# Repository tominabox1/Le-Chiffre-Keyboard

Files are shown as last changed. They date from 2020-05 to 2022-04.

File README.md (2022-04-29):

# Le Chiffre (ironically, "the number" in French)
The purpose of the board is to provide a platform for MX and Choc ergo (Alps support too!) in one package for when ones wrists need a break. The board supports an RGB LED strip with DI on port F0. The board is also fitted with support for run-of-the-mill .91" OLED and EC11 rotary encoder.

Great thanks goes to Jake at P3D for really making the case amazing and open sourcing his work. Check him out at P3Dstore.com

Firmware for the keyboard is available here: https://github.com/qmk/qmk_firmware/tree/master/keyboards/tominabox1/le_chiffre

This project is open sourced with the GPL-3.0 license. The license conditionally allows for commercial use, modification, distribution, patent, and private use. Please take note of the license conditions before utilizing this project. 

## Bill of materials
You can copy this table when ordering PCBs. 
| Item # | *Ref Des | *Qty | *Mfg Part # | Description\Value | *Package |
|---|---|---|---|---|---|
| 1 | D1, D2, D3, D4, D5, D6, D7, D8, D9, D10, D11, D12, D13, D14, D15, D16, D17, D18, D19, D20, D21, D22, D23, D24, D25, D26, D27, D28, D29, D30, D31, D32, D33, D34, D35 | 35 | 1N4148W | | SOD-123 |
| 2 | R7, R8 | 2 | 0603WAF4701T5E | 4.7k | 0805 |
| 3 | R6, R5 | 2 | 0805W8F1002T5E | 10k | 0805 |
| 4 | R4, R3 | 2 | 0805W8F220JT5E | 22r | 0805 |
| 5 | R2, R1 | 2 | 0805W8F5101T5E | 5.1k | 0805 |
| 6 | SW1 | 1 | TS-1076S-A1B2 | SW_Push | SMD,5.2x5.2x1.5  |
| 7 | F1 | 1 | SMD0805-020 | | 0805 |
| 8 | C8 | 1 | GRM188R60J475KE19D | 4.7uF | 0603 |
| 9 | C7, C5, C2, C1 | 4 | GRM188R71H104KA93D | 0.1uF | 0603 |
| 10 | C6, C3 | 2 | GRM1882C1H220JA01D | 22pf | 0603 |
| 11 | C4 | 1 | CC0603KRX5R6BB105  | 1uF | 0603 |
| 12 | Y1 | 1 | X322516MLB4SI | 16MHz | 3.2x2.5mm, 4 pad |
| 13 | U1 | 1 | ATMEGA32U4-AU | | 44-TQFP |
| 14 | USB1 | 1 | TYPE-C-31-M-12 | | |
| 15 | D111, D110, D109, D108, D107, D106, D105, D104, D103, D102, D101 | 11 | WS2812B-B | | LED-4_5050 |

# Fab files
If you just want to order PCBs and plates, just grab these files and send them to your fab house. Also include the BOM from above.

[PCB](KiCad/Le%20Chiffre%20v2/Fab/PCB/LeChiffrePCBFab.zip)

[Plate](KiCad/Le%20Chiffre%20v2/Fab/Plate/LeChiffrePlateFab.zip) (this is for one side, order 2 for each PCB)

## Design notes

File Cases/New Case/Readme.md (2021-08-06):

This case uses m2 heatset inserts on the top and m2 hardware for the bottom. Print with large flat faces on the print bed. I suggest using internal brim on the top piece so that the sharp corners do not curl.

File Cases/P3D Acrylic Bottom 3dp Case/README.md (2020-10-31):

# Le Chiffre

Le Chiffre
This is the STL for the Le Chiffre keyboard designed by tominabox1 (discord @tominabox1#7884)

This model is designed for MX switches and the fr4 plates provided in the group buy(s). Feel free to modify as you wish!

Visit the QMK page for firmware information.

P3D Mod Cases do not have the option for an OLED cover. They use 8 m2x8mm screws
Print them Top Down on the bed.
The Incline bottom is printed with the top part down, and the USB bump is bridged. No supports needed. 

Optionally, for the P3D cases, an OLED bezel designed by u/bomtarnes can be printed and friction fitted (chiffoled3.stl).

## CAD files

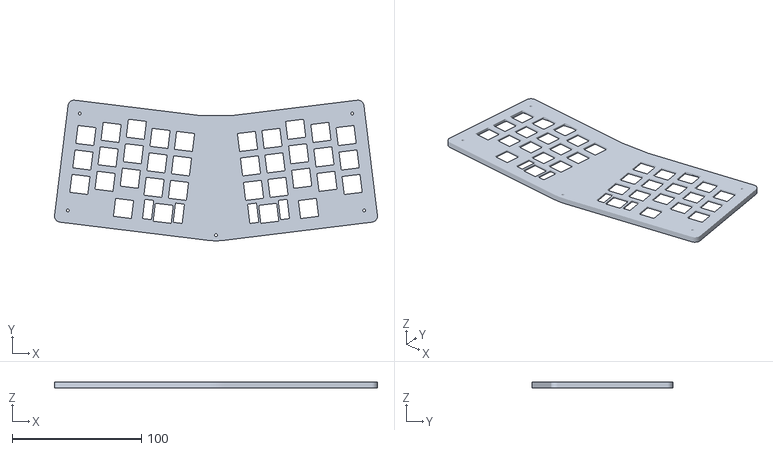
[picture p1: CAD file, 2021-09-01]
Cases/New Case/Plate.stl
249.6 x 108.7 x 4.50

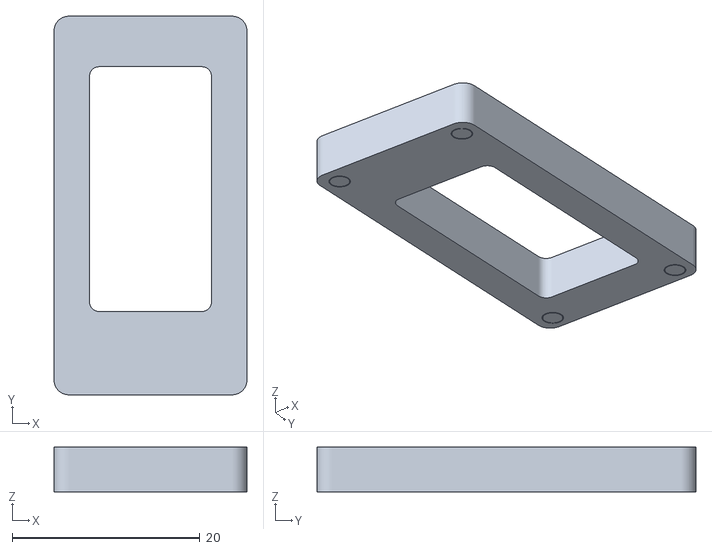
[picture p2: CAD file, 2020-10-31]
Cases/OG Case/chiffoled3.stl
20.6 x 40.4 x 4.79

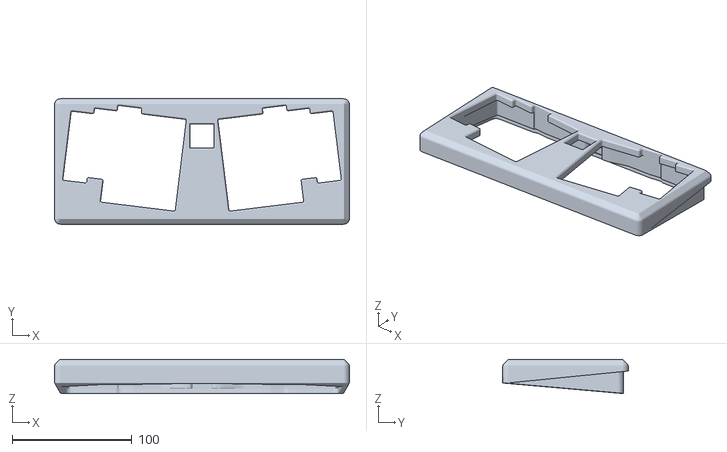
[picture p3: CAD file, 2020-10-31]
Cases/P3D Acrylic Bottom 3dp Case/Le Chiffre MX Cutout No OLED Cutout acrylic bottom.stl
246.5 x 104.9 x 28.5

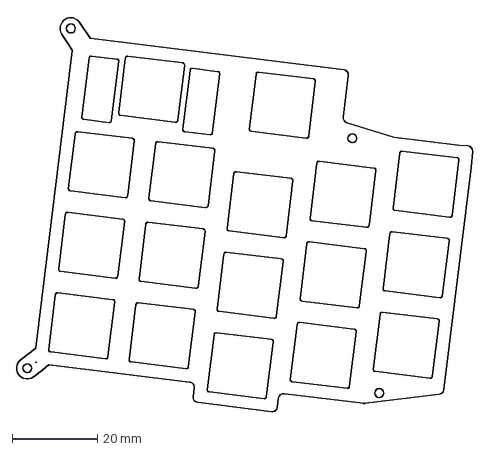
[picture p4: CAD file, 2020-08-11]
KiCad/Le Chiffre v2/LeChiffre_Plate/Plate 5.14.32 PM.dxf
107.2 x 92.9 mm

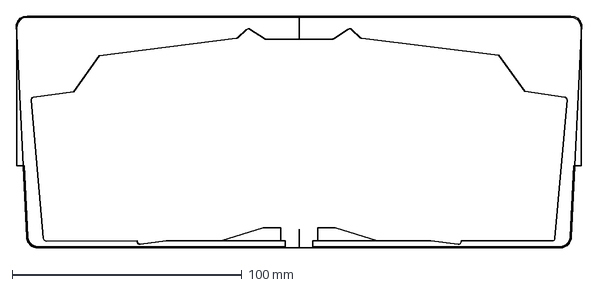
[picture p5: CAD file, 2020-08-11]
KiCad/Le Chiffre v2/plate.dxf
246.1 x 100.9 mm

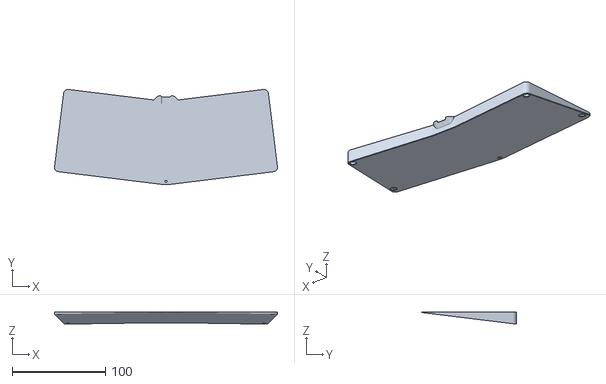
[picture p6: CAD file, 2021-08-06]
Cases/New Case/Bottom.stl
239.5 x 102.1 x 13.1

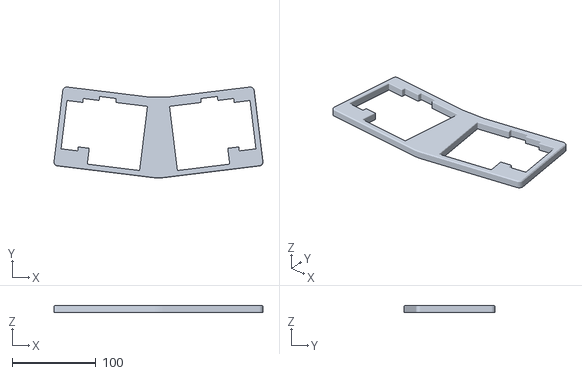
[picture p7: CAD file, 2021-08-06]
Cases/New Case/Top.stl
249.6 x 108.7 x 8.00

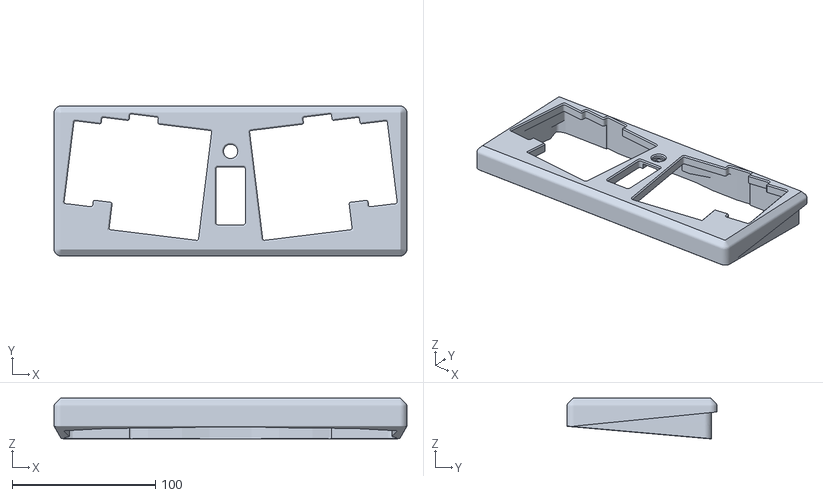
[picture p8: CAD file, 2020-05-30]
Cases/OG Case/Le Chiffre Incline top No Cover P3D Mod.stl
246.5 x 104.9 x 28.5

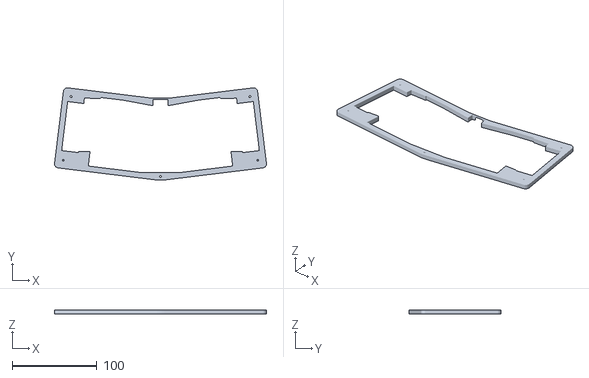
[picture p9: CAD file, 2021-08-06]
Cases/New Case/Bottom Mid.stl
249.6 x 108.7 x 5.00

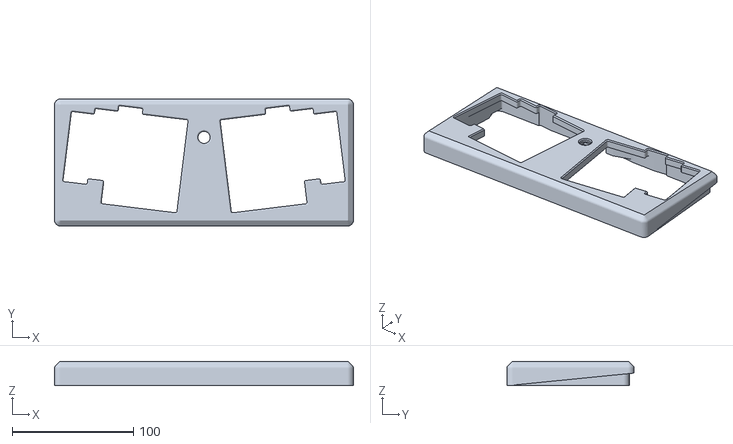
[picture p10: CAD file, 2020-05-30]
Cases/OG Case/Le Chiffre Flat Top with Cover P3D Mod.stl
246.5 x 104.9 x 20.1

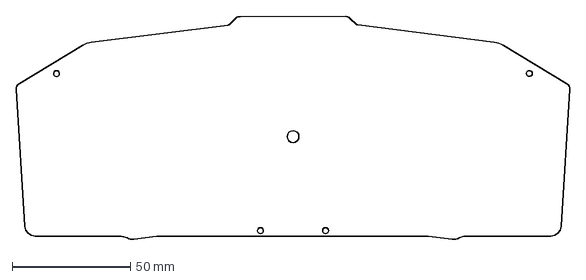
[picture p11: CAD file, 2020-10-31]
Cases/P3D Acrylic Bottom 3dp Case/Acrylic Bottom Le Chiffre P3D Mod v7.dxf
234.3 x 94.4 mm

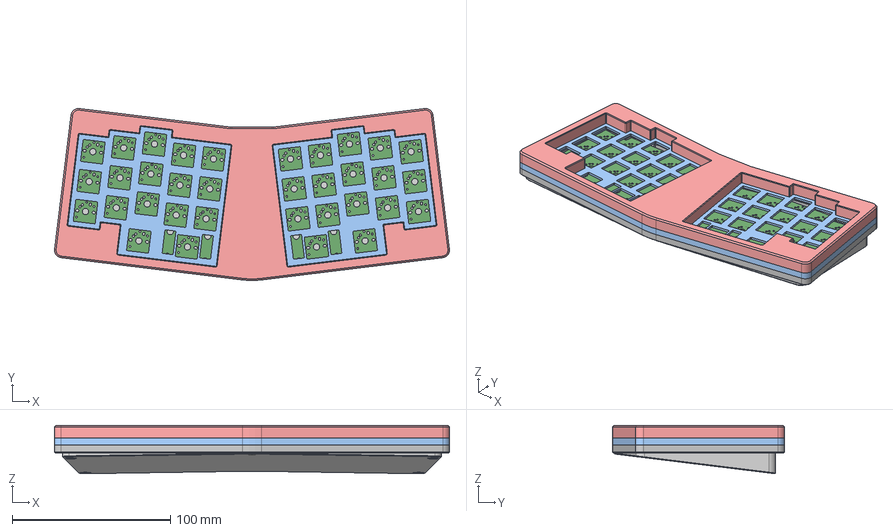
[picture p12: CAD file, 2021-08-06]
Cases/New Case/Le Chiffre New 2021.step
249.6 x 108.7 x 30.6 mm
HRO TYPE-C-31-M-12

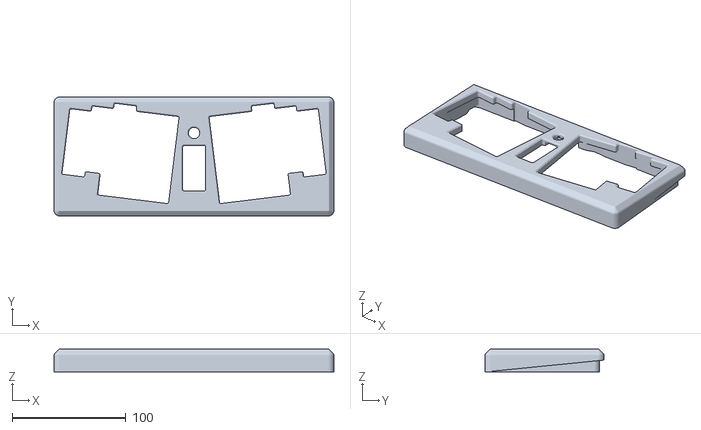
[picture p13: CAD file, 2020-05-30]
Cases/OG Case/Le Chiffre Flat Top No Cover P3D Mod.stl
246.5 x 104.9 x 20.1

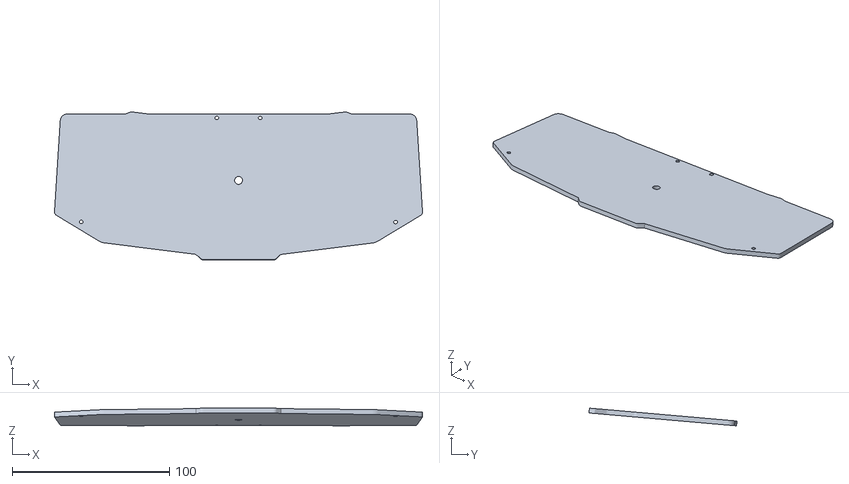
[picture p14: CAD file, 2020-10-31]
Cases/P3D Acrylic Bottom 3dp Case/Le Chiffre Acylic Bottom stl.stl
234.2 x 94.2 x 11.3

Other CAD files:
Cases/OG Case/Le Chiffre Incline top with Cover P3D Mod.stl
Cases/P3D Acrylic Bottom 3dp Case/Le Chiffre Rotary No OLED Cutout Acrylic Bottom.stl
Cases/P3D Acrylic Bottom 3dp Case/Le Chiffre Rotary OLED Cutout Acrylic Bottom.stl
Cases/OG Case/Le Chiffre Incline Bottom P3D Mod.stl
Cases/OG Case/Bottom Left.stl
Cases/OG Case/Le Chiffre v16.step
Cases/OG Case/bottom Right.stl
Cases/P3D Acrylic Bottom 3dp Case/Le Chiffre MX Cutout OLED Cutout acrylic bottom.stl

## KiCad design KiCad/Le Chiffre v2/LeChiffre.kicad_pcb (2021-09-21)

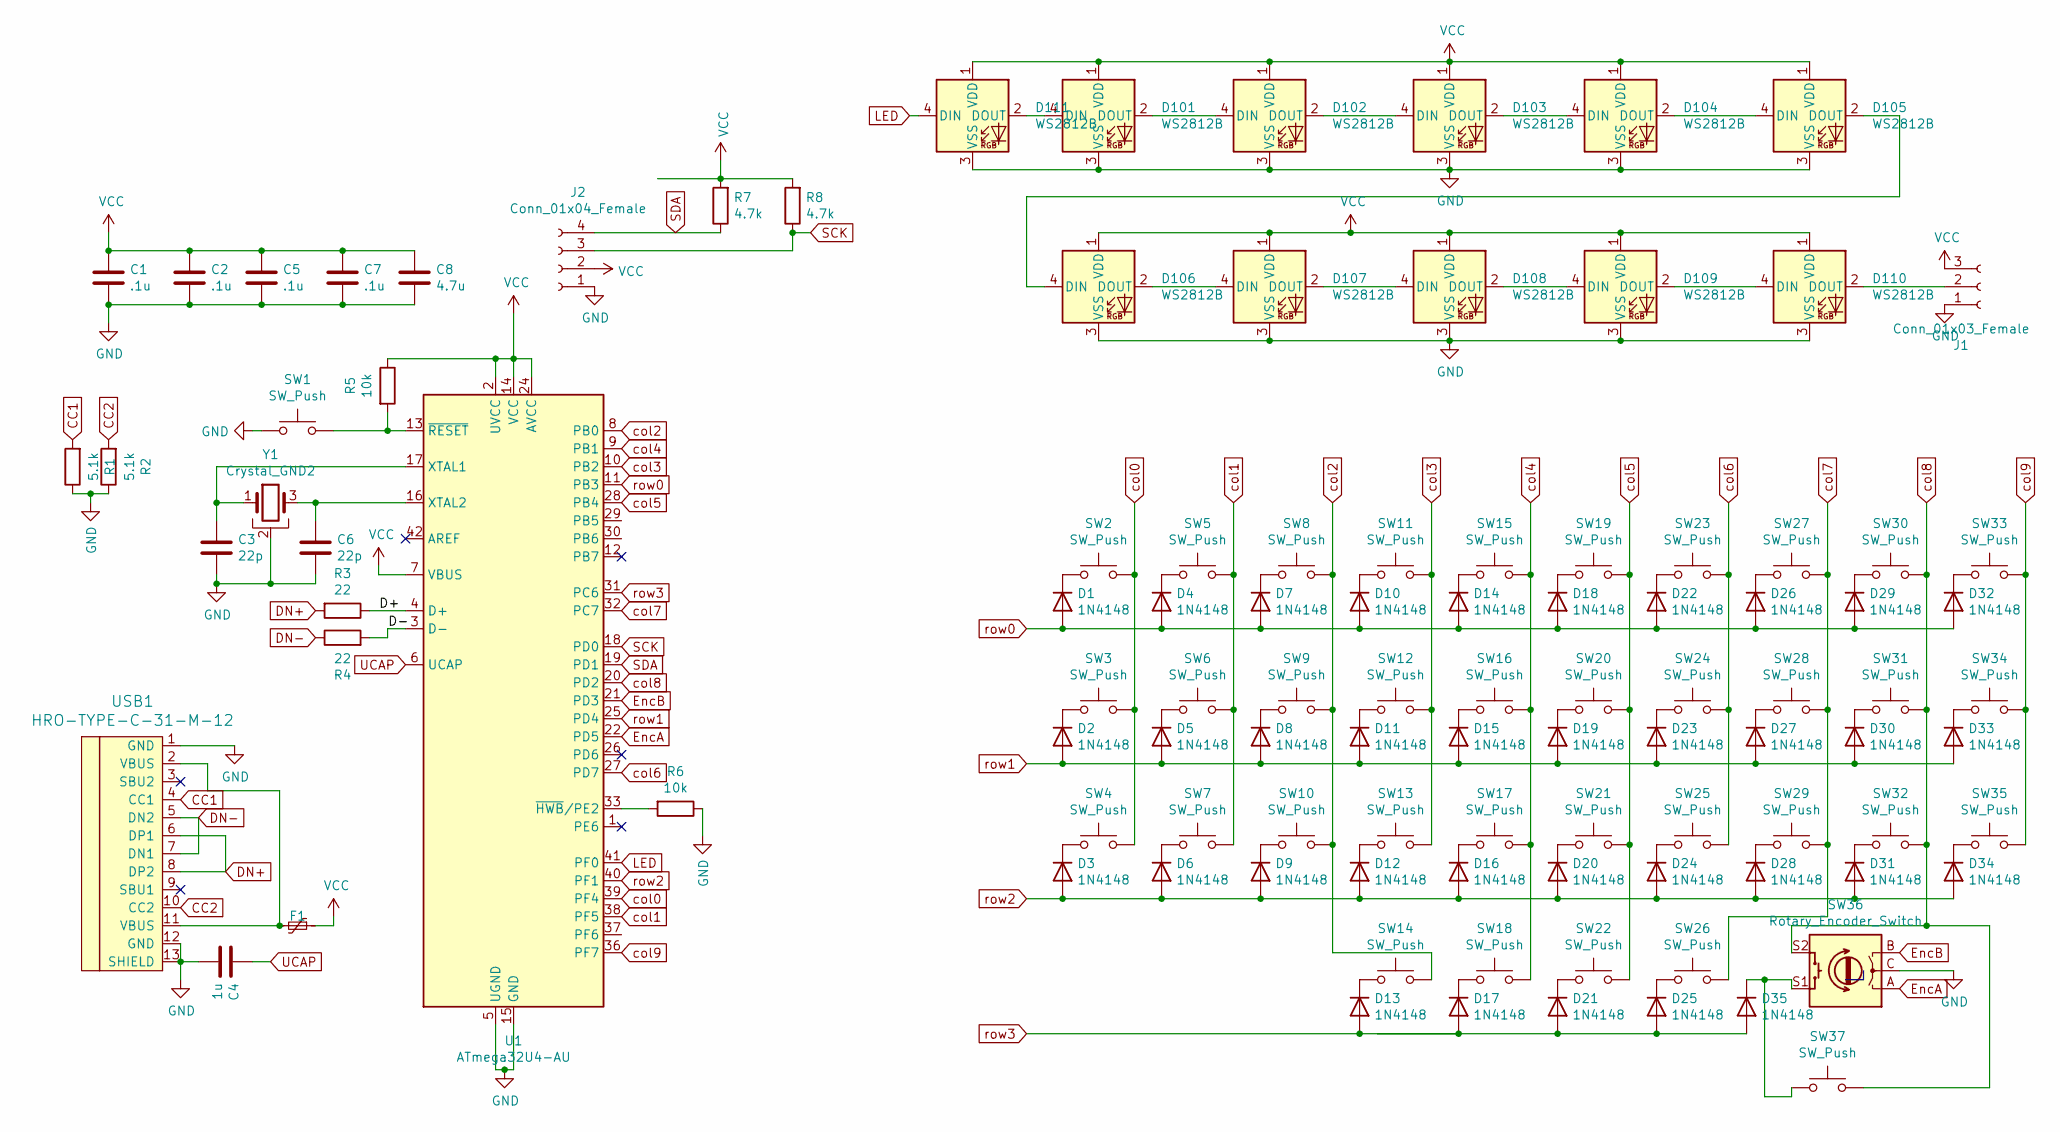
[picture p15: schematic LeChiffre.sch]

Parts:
C1, C2, C5, C7: .1u; C_0603
C3, C6: 22p; C_0603
C4: 1u; C_0603
C8: 4.7u; C_0603
D1, D2, D3, D4, D5, D6, D7, D8, D9, D10, D11, D12, D13, D14, D15, D16, D17, D18, D19, D20, D21, D22, D23, D24, D25, D26, D27, D28, D29, D30, D31, D32, D33, D34, D35: 1N4148; D_SOD123
D101, D102, D103, D104, D105, D106, D107, D108, D109, D110, D111: WS2812B; LED_WS2812B_PLCC4_5.0x5.0mm_P3.2mm
F1: Polyfuse_Small; Fuse_0805
J1: Conn_01x03_Female; PinSocket_1x03_P2.54mm_Vertical
J2: Conn_01x04_Female; PinSocket_1x04_P2.54mm_Vertical
R1, R2: 5.1k; R_0805
R3, R4: 22; R_0805
R5, R6: 10k; R_0805
R7, R8: 4.7k; R_0805
SW1: SW_Push; SW_SPST_TL3342
SW2, SW3, SW4, SW5, SW6, SW7, SW8, SW9, SW10, SW11, SW12, SW13, SW14, SW15, SW16, SW17, SW19, SW20, SW21, SW23, SW24, SW25, SW26, SW27, SW28, SW29, SW30, SW31, SW32, SW33, SW34, SW35, SW37: SW_Push; MX-Alps-Choc-1U-NoLED
SW18, SW22: SW_Push; MX-Alps-Choc-2U-StabFlip
SW36: Rotary_Encoder_Switch; RotaryEncoder_Alps_EC12E-Switch_Vertical_H20mm_CircularMoun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
U1: ATmega32U4-AU; ATMEGA32U4-AU
USB1: HRO-TYPE-C-31-M-12; HRO-TYPE-C-31-M-12-HandSoldering
Y1: Crystal_GND2; Crystal_SMD_3225-4pin_3.2x2.5mm

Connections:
/D+: R3.1, U1.4 (D+)
/D-: R4.2, U1.3 (D-)
CC1: R1.2, USB1.4 (CC1)
CC2: R2.2, USB1.10 (CC2)
DN+: R3.2, USB1.6 (DP1), USB1.8 (DP2)
DN-: R4.1, USB1.5 (DN2), USB1.7 (DN1)
EncA: SW36.A, U1.22 (PD5)
EncB: SW36.B, U1.21 (PD3)
GND: C1.2, C2.2, C3.2, C4.2, C5.2, C6.2, C7.2, C8.2, D101.3 (VSS), D102.3 (VSS), D103.3 (VSS), D104.3 (VSS), D105.3 (VSS), D106.3 (VSS), D107.3 (VSS), D108.3 (VSS), D109.3 (VSS), D110.3 (VSS), D111.3 (VSS), J1.1 (Pin_3), J2.1, R1.1, R2.1, R6.1, SW1.1, SW36.C, U1.5 (UGND), U1.15 (GND), U1.23 (GND), U1.35 (GND), U1.43 (GND), USB1.1 (GND), USB1.12 (GND), USB1.13 (SHIELD), Y1.2
LED: D111.4 (DIN), U1.41 (PF0)
unnamed: C3.1, U1.17 (XTAL1), Y1.1
unnamed: C6.1, U1.16 (XTAL2), Y1.3
unnamed: D1.1 (K), SW2.1
unnamed: D2.1 (K), SW3.1
unnamed: D3.1 (K), SW4.1
unnamed: D4.1 (K), SW5.1
unnamed: D5.1 (K), SW6.1
unnamed: D6.1 (K), SW7.1
unnamed: D7.1 (K), SW8.1
unnamed: D8.1 (K), SW9.1
unnamed: D9.1 (K), SW10.1
unnamed: D10.1 (K), SW11.1
unnamed: D11.1 (K), SW12.1
unnamed: D12.1 (K), SW13.1
unnamed: D13.1 (K), SW14.1
unnamed: D14.1 (K), SW15.1
unnamed: D15.1 (K), SW16.1
unnamed: D16.1 (K), SW17.1
unnamed: D17.1 (K), SW18.1
unnamed: D18.1 (K), SW19.1
unnamed: D19.1 (K), SW20.1
unnamed: D20.1 (K), SW21.1
unnamed: D21.1 (K), SW22.1
unnamed: D22.1 (K), SW23.1
unnamed: D23.1 (K), SW24.1
unnamed: D24.1 (K), SW25.1
unnamed: D25.1 (K), SW26.1
unnamed: D26.1 (K), SW27.1
unnamed: D27.1 (K), SW28.1
unnamed: D28.1 (K), SW29.1
unnamed: D29.1 (K), SW30.1
unnamed: D30.1 (K), SW31.1
unnamed: D31.1 (K), SW32.1
unnamed: D32.1 (K), SW33.1
unnamed: D33.1 (K), SW34.1
unnamed: D34.1 (K), SW35.1
unnamed: D35.1 (K), SW36.S1, SW37.1
unnamed: D101.2 (DOUT), D102.4 (DIN)
unnamed: D101.4 (DIN), D111.2 (DOUT)
unnamed: D102.2 (DOUT), D103.4 (DIN)
unnamed: D103.2 (DOUT), D104.4 (DIN)
unnamed: D104.2 (DOUT), D105.4 (DIN)
unnamed: D105.2 (DOUT), D106.4 (DIN)
unnamed: D106.2 (DOUT), D107.4 (DIN)
unnamed: D107.2 (DOUT), D108.4 (DIN)
unnamed: D108.2 (DOUT), D109.4 (DIN)
unnamed: D109.2 (DOUT), D110.4 (DIN)
unnamed: D110.2 (DOUT), J1.2
unnamed: F1.2, USB1.2 (VBUS), USB1.11 (VBUS)
unnamed: R5.2, SW1.2, U1.13 (~RESET)
unnamed: R6.2, U1.33 (~HWB~/PE2)
SCK: J2.3, R8.1, U1.18 (PD0)
SDA: J2.4, R7.1, U1.19 (PD1)
UCAP: C4.1, U1.6 (UCAP)
VCC: C1.1, C2.1, C5.1, C7.1, C8.1, D101.1 (VDD), D102.1 (VDD), D103.1 (VDD), D104.1 (VDD), D105.1 (VDD), D106.1 (VDD), D107.1 (VDD), D108.1 (VDD), D109.1 (VDD), D110.1 (VDD), D111.1 (VDD), F1.1, J1.3 (Pin_1), J2.2, R5.1, R7.2, R8.2, U1.2 (UVCC), U1.7 (VBUS), U1.14 (VCC), U1.24 (AVCC), U1.34 (VCC), U1.44 (AVCC)
col0: SW2.2, SW3.2, SW4.2, U1.39 (PF4)
col1: SW5.2, SW6.2, SW7.2, U1.38 (PF5)
col2: SW8.2, SW9.2, SW10.2, SW14.2, U1.8 (PB0)
col3: SW11.2, SW12.2, SW13.2, U1.10 (PB2)
col4: SW15.2, SW16.2, SW17.2, SW18.2, U1.9 (PB1)
col5: SW19.2, SW20.2, SW21.2, SW22.2, U1.28 (PB4)
col6: SW23.2, SW24.2, SW25.2, U1.27 (PD7)
col7: SW26.2, SW27.2, SW28.2, SW29.2, U1.32 (PC7)
col8: SW30.2, SW31.2, SW32.2, SW36.S2, SW37.2, U1.20 (PD2)
col9: SW33.2, SW34.2, SW35.2, U1.36 (PF7)
row0: D1.2 (A), D4.2 (A), D7.2 (A), D10.2 (A), D14.2 (A), D18.2 (A), D22.2 (A), D26.2 (A), D29.2 (A), D32.2 (A), U1.11 (PB3)
row1: D2.2 (A), D5.2 (A), D8.2 (A), D11.2 (A), D15.2 (A), D19.2 (A), D23.2 (A), D27.2 (A), D30.2 (A), D33.2 (A), U1.25 (PD4)
row2: D3.2 (A), D6.2 (A), D9.2 (A), D12.2 (A), D16.2 (A), D20.2 (A), D24.2 (A), D28.2 (A), D31.2 (A), D34.2 (A), U1.40 (PF1)
row3: D13.2 (A), D17.2 (A), D21.2 (A), D25.2 (A), D35.2 (A), U1.31 (PC6)

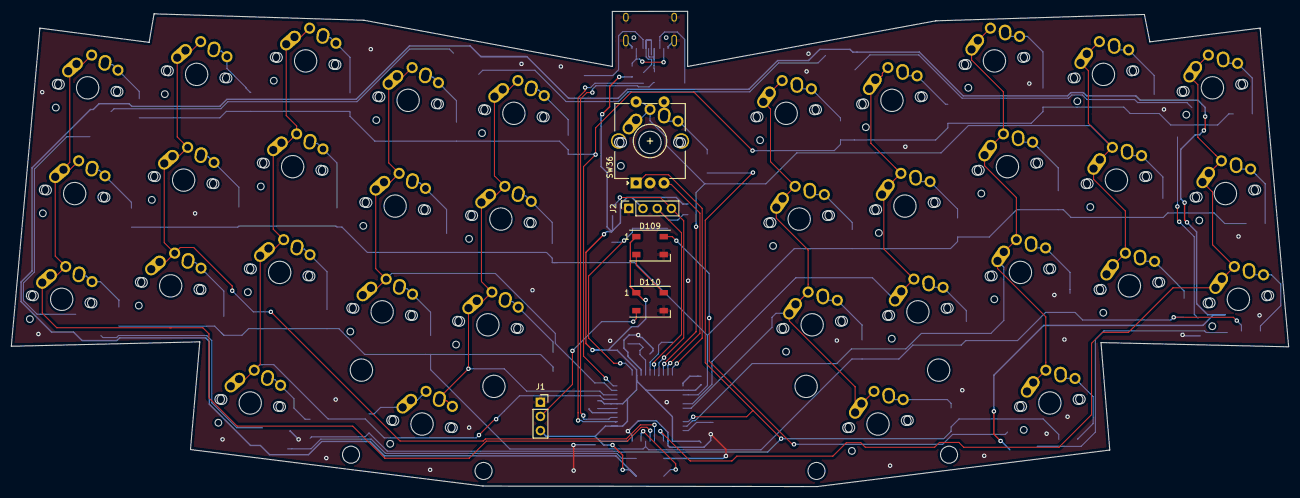
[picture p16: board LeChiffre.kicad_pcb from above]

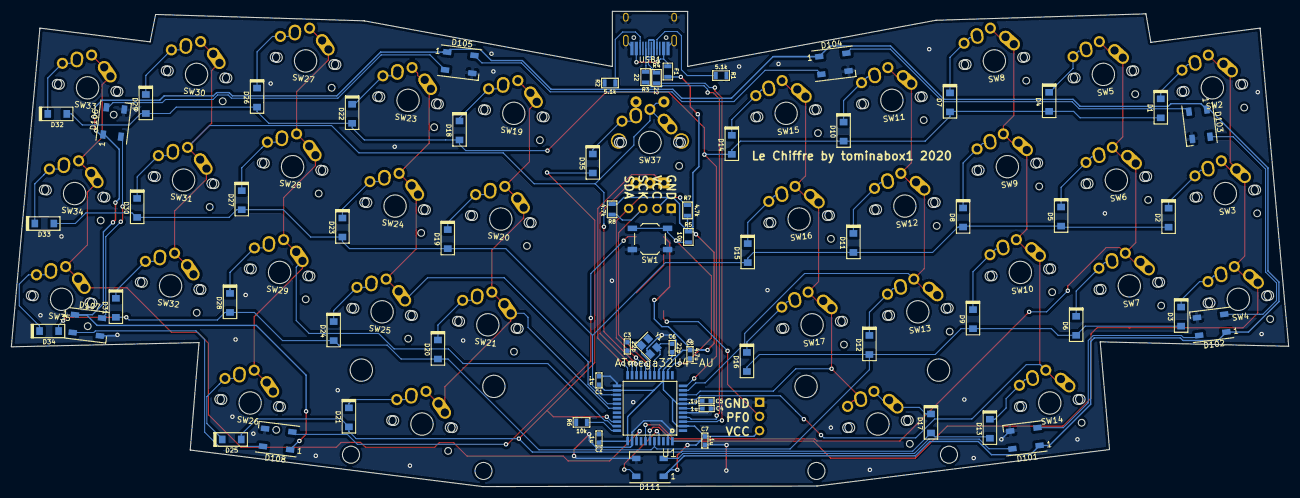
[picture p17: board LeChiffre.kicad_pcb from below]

Board: 2 copper layers, 228.4 x 85.0 mm, 105 parts (65 on the bottom side), 79 nets.

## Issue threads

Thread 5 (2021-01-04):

JLCPCB: SMT Assembly

Strech, 2021-01-04:
Hey, @tominabox1 thanks a lot for open-sourcing this amazing keeb. I'm trying to order the PCB and Plate in JLCPCB but I'm lacking knowledge about PCB parts.

When you order on JLCPCB they offer almost free SMT Assembly and they ask you about 2 things "BOM File" and "CPL File", do you have those? Or can you name components and their count to build the PCB?

tominabox1, 2021-01-05:
for what it's worth, there's a group buy going on right now at https://p3dstore.com. You may want to do this instead, it'd probably amount to a good savings (if you're in the US) over 5 assembled boards.

You'll need to export the BOM and part location file from the Kicad project https://support.jlcpcb.com/article/84-how-to-generate-the-bom-and-centroid-file-from-kicad

Strech, 2021-01-05:
Thanks for the GB link, unfortunately, I'm in the EU and the 35$ PCB will be converted to 80$ with delivery (before taxes, sic!). But I'm doing it not for saving money, but as a COVID lockdown hobby.

Strech, 2021-01-06:
@tominabox1 Sorry for bothering you again, I think I manage to understand most of the components on the board except 2

```
F1    Polyfuse_Small      Keebio-Parts:Fuse_0805
Y1    Crystal_GND2        Keebio-Parts:Crystal_SMD_3225-4pin_3.2x2.5mm
```

I think I found [`Y1`](https://jlcpcb.com/parts/componentSearch?searchTxt=Crystal%20SMD%203225) and `F1`](https://jlcpcb.com/parts/componentSearch?searchTxt=fuse%200805) but there are so many options. May I ask you to help me to choose them?

tominabox1, 2021-01-06:
This fuse should be good
https://lcsc.com/product-detail/Surface-Mount-Fuses_0-5A-6V-Self-healing-fuse_C66452.html/?href=jlc-SMT

This crystal
https://lcsc.com/product-detail/SMD-Crystal-Resonators_Yangxing-Tech-X322516MRB4SI_C70562.html/?href=jlc-SMT

Strech, 2021-01-06:
Thanks, I appreciate your help, was a bit challenging for me to understand how to use Kicad and Eeschema, if you want I can try to open PR with a filled LCSC field and/or BOM files

tominabox1, 2021-01-06:
feel free to open a PR

Strech, 2021-01-11:
@tominabox1 👋🏼 Hey, it's me ... again. The microcontroller which was specified unfortunately is out of stock on JLCPCB, and I'm not brave enough to just replace it with another. I tried comparing them, but I didn't see a severe difference (and my fear it's because I don't understand it).

May I ask you which chip can replace `ATMEGA32U4-AU` from [this list of ATMEGA32](https://jlcpcb.com/parts/componentSearch?searchTxt=ATMEGA32)? If none, then I will wait till they re-stock (check the stock column).

Closed 2021-01-05.

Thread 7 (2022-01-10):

duplicate mfg part numbers

dayofdoom, 2022-01-10:
Hello,

In the BOM on the main page, these two components have the same MFG part number but are listed as seperate components.

3 | R6, R5 | 2 | 0805W8J0103T5E | 10k | 0805
-- | -- | -- | -- | -- | --
4 | R4, R3 | 2 | 0805W8J0103T5E | 22r | 0805

Thank you

tominabox1, 2022-01-11:
Thanks for the report. I have updated the BOM with the correct numbers

dayofdoom, 2022-01-31:
Thank you!

Closed 2022-01-31.

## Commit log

2020-05-30 Added P3D Case Mods
    [Le Chiffre Flat Top No Cover P3D Mod.stl, Le Chiffre Flat Top with Cover P3D Mod.stl, Le Chiffre Incline Bottom P3D Mod.stl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]
2020-08-11 Adding kicad project
    [ErgoBoard.kicad_pcb, ErgoBoard.sch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]
2020-09-10 Add files via upload
    OLED bezel for P3D cases.
    [chiffoled3.stl]
2020-10-28 Add latest 3DP Case with Acrylic Bottom or 3DP Bottom
    [Acrylic Bottom Le Chiffre P3D Mod v7.dxf, Le Chiffre Acylic Bottom stl.stl, Le Chiffre MX Cutout No OLED Cutout acrylic bottom.stl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]
2020-10-31 Rename project to Le Chiffre. Update pcb with RGB LEDs on bottom and top. Clean up layout a bit. Remove gerber folders (please generate from the kicad file)
    [ErgoBoard.kicad_pcb, ErgoBoard.sch, LeChiffre.kicad_pcb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]
2020-10-31 Orgaize cases
    [Body.stl, Bottom Left.stl, Le Chiffre Flat Top No Cover P3D Mod.stl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]
2020-10-31 Move P3D new case into cases
    [Acrylic Bottom Le Chiffre P3D Mod v7.dxf, Le Chiffre Acylic Bottom stl.stl, Le Chiffre MX Cutout No OLED Cutout acrylic bottom.stl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]
2020-11-04 Update PCB
    [LeChiffre.kicad_pcb]
2021-08-05 added the bluetooth capable drop-in replacement PCB le_chiff_ble as a git submodule
2021-08-06 Added new 3dp case
    [Bottom Mid.stl, Bottom.stl, Le Chiffre New 2021.step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]
2021-08-06 reorganizing for the addition of ble submodule
    [LeChiffre.kicad_pcb, LeChiffre.sch, LeChiffre_Plate.kicad_pcb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]
2021-09-01 updated plate for room for RGB Chiffre designs
    [Plate.stl]
2021-09-21 Adding BOM and Gerber files
    [LeChiffre-B_Cu.gbr, LeChiffre-B_Fab.gbr, LeChiffre-B_Mask.gbr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]
